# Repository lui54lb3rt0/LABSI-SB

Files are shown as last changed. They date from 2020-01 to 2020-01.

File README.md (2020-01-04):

# LABSI Project
## Description of project
This project has made part of the LABSI Class of my BSc in Electrical and Computer Engineer degree and consists of a self-balancing robot.

## The robot :robot: 

The robot has made with several components from old label printers and mechanical trash.

The robot has two wheels attached to the stepper motors that are capable to move forward and backward the robot with PWM generated in the function of GYRO and Accelerometer positions from a PID controller developed to the uC.

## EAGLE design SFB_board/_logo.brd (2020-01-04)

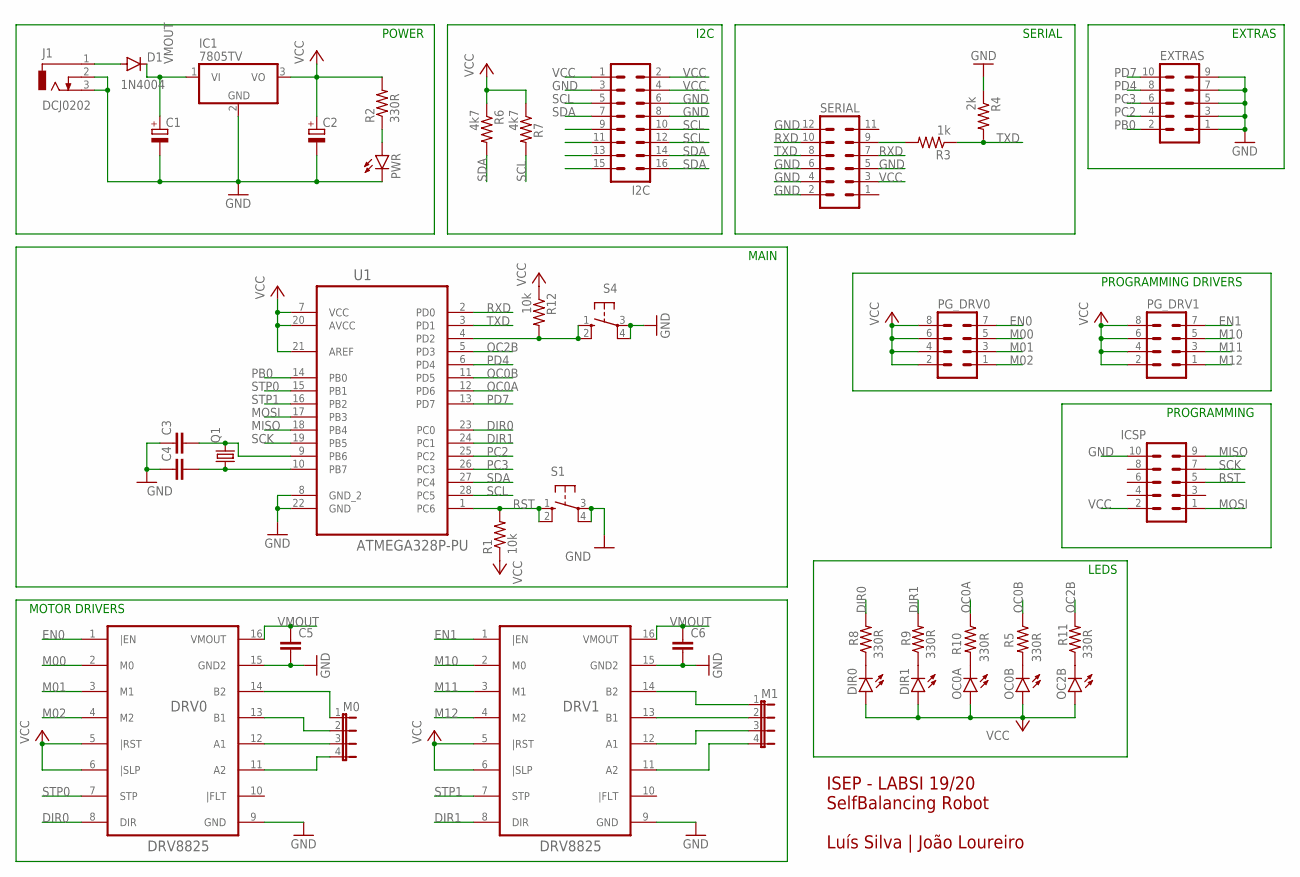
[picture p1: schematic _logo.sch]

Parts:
C1, C2: CPOL-EUB45181A; B45181A
C3, C4: C5/3; C5B3
C5, C6: C2.5/2; C2.5-2
D1: 1N4004; DO41-10
DIR0, DIR1: LED3MM
DRV0, DRV1: DRV8825
EXTRAS: ML10
I2C: MA08-2
IC1: 7805TV; TO220V
ICSP: ML10
J1: DCJ0202
M0, M1: JP4E; JP4
OC0A, OC0B, OC2B: LED3MM
PG_DRV0, PG_DRV1: MA04-2
PWR: LED3MM
Q1: CRYSTALHC49S; HC49/S
R1, R12: 10k; 0207/10
R2, R5, R8, R9, R10, R11: 330R; 0207/10
R3: 1k; 0207/10
R4: 2k; 0207/10
R6, R7: 4k7; 0207/10
S1, S4: 10-XX; B3F-10XX
SERIAL: MA06-2
U1: ATMEGA328P-PU; DIP254P762X457-28

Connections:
DIR0: DRV0.8 (DIR), R8.2, U1.23 (PC0)
DIR1: DRV1.8 (DIR), R9.2, U1.24 (PC1)
EN0: DRV0.1 (|EN), PG_DRV0.7
EN1: DRV1.1 (|EN), PG_DRV1.7
GND: C1.-, C2.-, C3.1, C4.1, C5.2, C6.2, DRV0.9 (GND), DRV0.15 (GND2), DRV1.9 (GND), DRV1.15 (GND2), EXTRAS.1, EXTRAS.3, EXTRAS.5, EXTRAS.7, EXTRAS.9, I2C.3, I2C.6, I2C.8, IC1.2 (GND), ICSP.10, J1.2, J1.3, PWR.K (C), R4.1, S1.3, S1.4 (P1), S4.3, S4.4 (P1), SERIAL.2, SERIAL.4, SERIAL.5, SERIAL.6, SERIAL.12, U1.8 (GND_2), U1.22 (GND)
M00: DRV0.2 (M0), PG_DRV0.5
M01: DRV0.3 (M1), PG_DRV0.3
M02: DRV0.4 (M2), PG_DRV0.1
M10: DRV1.2 (M0), PG_DRV1.5
M11: DRV1.3 (M1), PG_DRV1.3
M12: DRV1.4 (M2), PG_DRV1.1
MISO: ICSP.9, U1.18 (PB4)
MOSI: ICSP.1, U1.17 (PB3)
unnamed: DRV0.14 (B2), M0.1
unnamed: PWR.A, R2.1
unnamed: D1.A, J1.1
unnamed: C4.2, Q1.1, U1.10 (PB7)
unnamed: C3.2, Q1.2, U1.9 (PB6)
unnamed: R3.2, SERIAL.9
unnamed: OC0B.K (C), R5.2
unnamed: DIR0.K (C), R8.1
unnamed: DIR1.K (C), R9.1
unnamed: OC0A.K (C), R10.2
unnamed: OC2B.K (C), R11.1
unnamed: DRV0.13 (B1), M0.2
unnamed: DRV0.12 (A1), M0.3
unnamed: DRV0.11 (A2), M0.4
unnamed: DRV1.14 (B2), M1.1
unnamed: DRV1.13 (B1), M1.2
unnamed: DRV1.12 (A1), M1.3
unnamed: DRV1.11 (A2), M1.4
OC0A: R10.1, U1.12 (PD6)
OC0B: R5.1, U1.11 (PD5)
OC2B: R11.2, U1.5 (PD3)
PB0: EXTRAS.2, U1.14 (PB0)
PC2: EXTRAS.4, U1.25 (PC2)
PC3: EXTRAS.6, U1.26 (PC3)
PD4: EXTRAS.8, U1.6 (PD4)
PD7: EXTRAS.10, U1.13 (PD7)
RST: ICSP.5, R1.2, S1.1 (S), S1.2 (S1), U1.1 (PC6)
RST1: R12.2, S4.1 (S), S4.2 (S1), U1.4 (PD2)
RXD: SERIAL.7, SERIAL.10, U1.2 (PD0)
SCK: ICSP.7, U1.19 (PB5)
SCL: I2C.5, I2C.10, I2C.12, R7.2, U1.28 (PC5)
SDA: I2C.7, I2C.14, I2C.16, R6.2, U1.27 (PC4)
STP0: DRV0.7 (STP), U1.15 (PB1)
STP1: DRV1.7 (STP), U1.16 (PB2)
TXD: R3.1, R4.2, SERIAL.8, U1.3 (PD1)
VCC: C2.+, DIR0.A, DIR1.A, DRV0.5 (|RST), DRV0.6 (|SLP), DRV1.5 (|RST), DRV1.6 (|SLP), I2C.1, I2C.2, I2C.4, IC1.3 (VO), ICSP.2, OC0A.A, OC0B.A, OC2B.A, PG_DRV0.2, PG_DRV0.4, PG_DRV0.6, PG_DRV0.8, PG_DRV1.2, PG_DRV1.4, PG_DRV1.6, PG_DRV1.8, R1.1, R2.2, R6.1, R7.1, R12.1, SERIAL.3, U1.7 (VCC), U1.20 (AVCC), U1.21 (AREF)
VMOUT: C1.+, C5.1, C6.1, D1.C, DRV0.16 (VMOUT), DRV1.16 (VMOUT), IC1.1 (VI)

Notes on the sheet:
POWER
PROGRAMMING
ISEP - LABSI 19/20 SelfBalancing Robot Luís Silva | João Loureiro
I2C
SERIAL
EXTRAS
PROGRAMMING DRIVERS
LEDS
MAIN
MOTOR DRIVERS

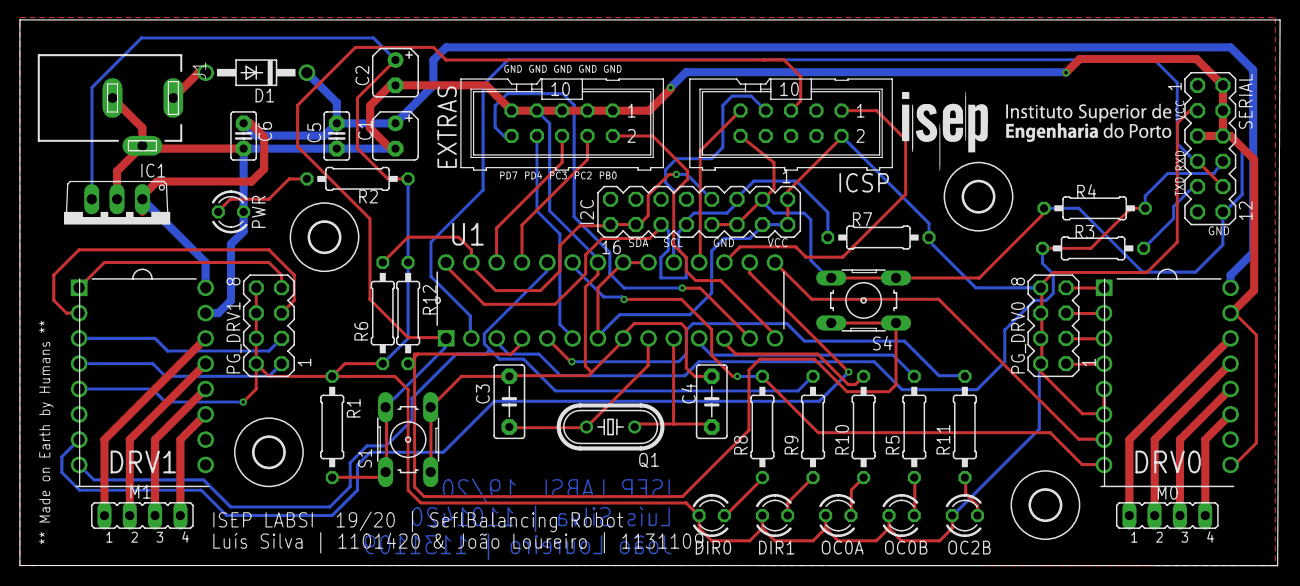
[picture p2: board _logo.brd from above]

Board: 2 copper layers, 126.5 x 54.8 mm, 45 parts (0 on the bottom side), 50 nets.

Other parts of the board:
U$1, U$2, U$3, U$4: 3,0

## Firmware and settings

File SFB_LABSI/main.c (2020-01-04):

/********************************************************
Language            :      C
Year                :      2019/2020
Class               :      LABSI
Authors             :      Luis Silva | Joao Loureiro
E-mail              :      1101420@isep.ipp.pt | 1131109@isep.ipp.pt
*********************************************************/

#define F_CPU 16000000UL								/* Define CPU clock Frequency e.g. here its 16MHz */
#include <avr/io.h>										/* Include AVR std. library file */
#include <avr/interrupt.h>								/* Include AVR interrupt library file */
#include <util/delay.h>									/* Include delay header file */
#include <inttypes.h>									/* Include integer type header file */
#include <stdlib.h>										/* Include standard library file */
#include <stdio.h>
#include <stdint.h>
#include "MPU6050_res_define.h"							/* Include MPU6050 register define file */
#include "I2C_Master_H_file.h"							/* Include I2C Master header file */

typedef struct USARTRX
{
	char receiver_buffer;
	unsigned char status;
	unsigned char receive 	: 1;
	unsigned char error	: 1;

}USARTRX_st;

volatile USARTRX_st rxUSART = {0,0,0,0};
char TxBuffer[50];
char float_[10];

/* Functions */

void SendMessage(char * buffer)
{
	unsigned char i=0;
	while(buffer[i]!='\0')
	{
		while((UCSR0A & 1<<UDRE0)==0);
		UDR0=buffer[i];
		i++;
	}
}

volatile uint8_t timerFlag = 0;
volatile float Acc_x,Acc_y,Acc_z,Temperature,Gyro_x,Gyro_y,Gyro_z;
volatile int ledCounter = 0;

float Acceleration_angle[2];
float Gyro_angle[2];
float Total_angle[2];

float elapsedTime = 0.001408;							//TS - time sample
float rad_to_deg = 180/3.141592654;

int PWM, error, previous_error;
float pid_p=0;
float pid_i=0;
float pid_d=0;
float pid_tot=0;
float previous_pid_tot = 0;

/////////////////PID CONSTANTS/////////////////
float kp = 0;
float ki = 0;
float kd = 0;
///////////////////////////////////////////////

float desired_angle = 0;								//This is the angle in which we want the balance to stay steady

/* Functions start here */
void inic()
{
	
	DDRC = 0x0F;										// Set PC0 & PC1 as output to Motor direction & scope test probes
	DDRB = 0x06;										// Set PB1 and PB2 as output OC1A & OC1B
	DDRD = (1<<DDD3) | (1<<DDD4) | (1<<DDD5) | (1<<DDD6) ;

	PORTD = (0<<DDD2) | (1<<DDD3)  | (1<<DDD5) | (1<<DDD6);
	PORTC = 0b00000011;

	/* Timer 1 */
	TCCR1A = ((1 << COM1A0) | (1 << COM1B0));			// Enable OC1A e OC1B to motors
	TCCR1B = ((1 << CS12) | (1 << WGM12));				// CLKIO/256 (From prescaler) | Mode CTC
	OCR1A = 65535;										// motor speed right
	OCR1B = 65535;										// motor speed left


	/* Timer 2 */
	TCCR2A = (1<<WGM21);								// MODE CTC
	TCCR2B = ((1 << CS21) | (1 << CS22));				// CLKIO/256 (From prescaler)
	TIMSK2 = (1 << OCIE2A);								// Enable TIMER0
	OCR2A = 88;											// ~0.001088s  ~900Hz    68

	/* USART */
	UBRR0H=0;
	UBRR0L=51;											// BAUDRATE 38400
	UCSR0A=(1<<U2X0);									// Double Speed
	UCSR0B=(1<<RXCIE0)|(1<<RXEN0)|(1<<TXEN0);			// RX Complete Interrupt Enable, Receiver Enable; transmite Enable
	UCSR0C=(1<<UCSZ01)|(1<<UCSZ00);						// 8 bits
	
	sei();
	
	sprintf(TxBuffer, "Init successfully!!!\r\n");
	SendMessage(TxBuffer);

}

void MPU6050_Init()                                     /* Gyro initialization function */
{
	_delay_ms(250);										/* Power up time >100ms */
	I2C_Start_Wait(0xD0);								/* Start with device write address */
	I2C_Write(SMPLRT_DIV);								/* Write to sample rate register */
	I2C_Write(0x07);									/* 1KHz sample rate */
	I2C_Stop();

	I2C_Start_Wait(0xD0);
	I2C_Write(PWR_MGMT_1);                              /* Write to power management register */
	I2C_Write(0x01);                                    /* X axis gyroscope reference frequency */
	I2C_Stop();

	I2C_Start_Wait(0xD0);
	I2C_Write(CONFIG);                                  /* Write to Configuration register */
	I2C_Write(0x00);                                    /* Fs = 8KHz */
	I2C_Stop();

	I2C_Start_Wait(0xD0);
	I2C_Write(GYRO_CONFIG);								/* Write to Gyro configuration register */
	I2C_Write(0x18);                                    /* Full scale range +/- 2000 degree/C */
	I2C_Stop();

	I2C_Start_Wait(0xD0);
	I2C_Write(INT_ENABLE);								/* Write to interrupt enable register */
	I2C_Write(0x01);
	I2C_Stop();
}

void MPU_Start_Loc()
{
	I2C_Start_Wait(0xD0);								/* I2C start with device write address */
	I2C_Write(ACCEL_XOUT_H);							/* Write start location address from where to read */
	I2C_Repeated_Start(0xD1);							/* I2C start with device read address */
}

void Read_RawValue()
{
	
	MPU_Start_Loc();            /* Read Gyro values */
	Acc_x = (((int)I2C_Read_Ack()<<8) | (int)I2C_Read_Ack());
	Acc_y = (((int)I2C_Read_Ack()<<8) | (int)I2C_Read_Ack());
	Acc_z = (((int)I2C_Read_Ack()<<8) | (int)I2C_Read_Ack());
	Gyro_x = (((int)I2C_Read_Ack()<<8) | (int)I2C_Read_Ack());
	Gyro_y = (((int)I2C_Read_Ack()<<8) | (int)I2C_Read_Ack());
	Gyro_z = (((int)I2C_Read_Ack()<<8) | (int)I2C_Read_Nack());
	I2C_Stop();

}

void AngleCalc()
{
	//---ACC  Y---
	Acceleration_angle[1] = atan(-1*(Acc_x/16384.0)/sqrt(pow((Acc_y/16384.0),2) + pow((Acc_z/16384.0),2)))*rad_to_deg;

	//---GYRO Y---
	Gyro_angle[1] = Gyro_y/131.0;
	
	//Complementary Filter
	//---Y axis angle--- Pitch
	Total_angle[1] = 0.98 *(Total_angle[1] + Gyro_angle[1]*elapsedTime) + 0.02*Acceleration_angle[1];
}

float sat(float _pid, int umin, int umax)
{
	if (_pid <= umin)
	{
		_pid = umin;
	}

	if (_pid >= umax)
	{
		_pid = umax;
	}
	return _pid;
}

void PID()
{
	error = Total_angle[1] - desired_angle;
	
	pid_i =+ki*(error+previous_error);
	pid_i = sat(pid_i,-1.5,2);
	pid_tot = previous_pid_tot + kp* (error-previous_error) + pid_i;
	
	//change motors direction
	if (error < 0)
	{
		PORTC = 0b00000000;
	}
	if (error >= 0)
	{
		PORTC = 0b00000011;
	}
	
	pid_tot = sat(pid_tot,-9,9);		//-10 10
	
	previous_error = error;
	previous_pid_tot = pid_tot;
	
}


int main()
{
	inic();                                              // Main configurations
	_delay_ms(500);
	I2C_Init();                                          // Initialize I2C
	MPU6050_Init();                                      // Initialize MPU6050
	desired_angle = 0;
	kp =0.55;
	ki = ((kp/0.9)*(elapsedTime/2));

	while(1)
	{
		//Set SETPOINT
		if((PIND & (1 << PIND2)) == 0 ) {
			OCR1A = 65535;
			OCR1B = 65535;
			desired_angle = Total_angle[1];
		}
		
		if (timerFlag==1)
		{
			Read_RawValue();							// Read gyro and acc from MPU6050
			AngleCalc();
			
			PID();
			
			PWM = 40.302*exp(-0.31*abs(pid_tot));		// Works well
			if ((error > -0.05) && (error <= 0.05)) PWM =10800;
			
			if ( (Total_angle[1] >= 0) && (Total_angle[1] <= 0.5)) {
				PWM = 65000;
			}
			else if ((Total_angle[1] >= -0.5) && (Total_angle[1] <= 0)) {
				PWM = 65000;
			}
			
			if ((Total_angle[1]>30) | (Total_angle[1]<-30))
			{
				PWM = 65535;
				pid_tot=0;
				pid_i=0;
				previous_error=0;
				previous_pid_tot=0;
			}


			if (TCNT1 >= PWM){
				TCNT1 = 0;
				OCR1A = PWM;
				OCR1B = PWM;
			}
			else
			{
				OCR1A = PWM;
				OCR1B = PWM;
			}
			
			timerFlag=0;
		}
	}
}


/* Interrupts */
ISR(TIMER2_COMPA_vect)
{
	
	if (timerFlag==0)
	{
		timerFlag=1;
	}
	if (ledCounter==500) {
		PORTD ^= (1<<DDD3);
		ledCounter = 0;
	}
	ledCounter ++;
}

ISR (USART_RX_vect)
{
	rxUSART.status = UCSR0A;
	if(rxUSART.status & ((1<<FE0) | (1<<DOR0) | (1<<UPE0)))
	rxUSART.error = 1;
	rxUSART.receiver_buffer = UDR0;
	rxUSART.receive = 1;
}
